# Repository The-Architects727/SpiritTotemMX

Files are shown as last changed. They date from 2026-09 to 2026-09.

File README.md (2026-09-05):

# SpiritTotemMX

A port of the [TOTEM](https://github.com/GEIGEIGEIST/TOTEM) split keyboard
to MX-style hot-swap switches, with a few of my own additions (per-half
battery-charge LEDs on the dongle, an on-demand battery check, and sleep
management for each half — see [Firmware](#firmware)).

This repo has everything needed to build one from scratch: the 3D-printable
case, the PCB design and fabrication files, ready-to-flash firmware, and
the full assembly guide below.

The layout is inspired by the original TOTEM — a printed test of that
shape was comfortable enough for my hands that I built the rest of this
board around it, redesigning the PCB and case for MX switches from
scratch. The XIAO boards sit on hot-swap headers rather than being
soldered in directly, so they can move to a different project later if
needed. Currently FDM printed in PLA with no tenting solution yet — both
are on the list for a future revision.

## Contents

- [What's in this repo](#whats-in-this-repo)
- [Bill of materials](#bill-of-materials)
- [Assembly](#assembly)
- [Keymap](#keymap)
- [Firmware](#firmware)
- [License](#license)

## What's in this repo

| Folder | Contents |
|---|---|
| [`Case/`](Case) | STL files for 3D printing the case and keycaps |
| [`PCB/`](PCB) | KiCad project source and fabrication-ready Gerbers/BOM/positions |
| [`Firmware/`](Firmware) | Pre-built `.uf2` firmware, ready to flash |

## Bill of materials

Links are the specific listings used for this build, not strict
requirements — quantities are usually a bulk pack, and most of these have
plenty of equivalent alternatives if a listing goes stale.

- 1 PCB — the left half, right half, and dongle are all panelized onto a
  single board you order as one piece (see [`PCB/`](PCB))
- 38× key switches — [Keychron Super Switch, tactile, 110-pack](https://www.amazon.com/dp/B0F9FJDWGZ)
- 38× Kailh hot-swap sockets — [Kailh CPG151101S11, 50-pack](https://www.amazon.com/dp/B0BVH6M5FP)
- 38× diodes (through-hole or SMD) — [1N4001, DO-41, 120-pack](https://www.amazon.com/dp/B0DN5YNFHQ)
  (1N4148 is the more common choice for keyboard matrices, but 1N4001 works
  fine here too)
- 3× Seeed Studio XIAO nRF52840 boards, with headers on —
  [Seeed Studio, 3-pack](https://www.seeedstudio.com/Seeed-Studio-XIAO-nRF52840-3PCS-p-5921.html)
- 2× JST 2.0 female wire connectors (battery leads for the two hand boards)
  and 4× JST 2.0 male PCB connectors — one kit covers both:
  [JST-PH 2.0mm 2-pin, male+female with 10cm wire, 20 sets](https://www.amazon.com/dp/B0D7Q9HJLQ)
- 2× through-hole PCB slide switches (mounted sideways so they poke out the
  side of the case) — [Chanzon SPDT 3mm slide switch, 70-pack](https://www.amazon.com/dp/B09R43HCY3)
- 2.54mm pitch headers for the XIAO standoffs — 60 pin positions total —
  [2.54mm male/female pin headers, 30-pack](https://www.amazon.com/dp/B0FCTSSLK9)
- 2× 3.7V JST 2.0 batteries, no more than 7mm thick × 20mm wide × 45mm long —
  [AKZYTUE 3.7V 750mAh LiPo, JST PH2.0](https://www.amazon.com/dp/B07TWHFW82)
- 2× 5mm LEDs
- 2× 330Ω resistors (through-hole or SMD)
- M2 brass heat-set inserts —
  [Pofsnnx M2 brass heat-set inserts, 250-pack](https://www.amazon.com/dp/B0FJXLNMLM)
- M2 screws: 6× 12mm, 1× 4mm —
  [KADRICK M2 hex socket button head screw assortment, 1000-pack](https://www.amazon.com/dp/B0DRCG3418)

## Assembly

### PCB and soldering

1. Break the panelized PCB apart into its 3 boards (left, right, dongle)
   along the mouse-bite tabs, and lightly sand the broken edges smooth.
2. Solder the diodes to the **top** face and the hot-swap sockets to the
   **underside**. The switchplate has cutouts to clear the diodes as long
   as they're soldered close to the board.
3. Solder the 2.54mm headers to the top face of each hand's board, where
   the XIAO will sit.
4. Solder the JST connectors and the slide power switch into place.
5. Solder a JST female connector pigtail to the underside of each hand's
   XIAO board, for its battery. This is the fiddliest step — put a small
   blob of solder on the pad first, then push the wire into the molten
   blob with the iron in one hand and a small pair of pliers in the other.
6. For the dongle: solder on the headers, then solder the two 5mm LEDs to
   the underside so they shine from the inside toward the outside edge,
   along with their resistors.

### Case

- `Top.stl` and `Bottom.stl` are single files — print one of each and
  mirror a second copy of each in your slicer for the other hand.
  `Switchplate.stl` and `Switchplate-left.stl` are **not** mirror images of
  each other — print each one exactly once.
- [`Case/KeyCaps/`](Case/KeyCaps) has the keycap profiles, designed to be
  printed flat on the bed while still having a swept (sculpted) profile —
  no supports needed despite the curve. Print 12× `Home`, 20×
  `Top-Bottom`, and 6× `Thumb` (38 keycaps total).
- Press a 2mm brass insert into the hole in the dongle base's dovetail.
- Press a heat-set insert into every standoff hole in each hand's bottom
  case piece.
- **Dongle:** drop the PCB+XIAO assembly into the bottom housing, slide the
  top piece on and push it forward to lock the board in place, then secure
  with a single M2×4mm screw.
- **Each hand:** place the PCB on the bottom case, then the switchplate
  over it (press a few switches into place to hold the sandwich together
  while you work), then the top plate, and secure with a 12–16mm screw in
  each top hole.

### First power-on

The dongle learns which half is "left" and which is "right" by whichever
one it bonds to first — so the very first time, power things on in this
order:

1. Everything off.
2. Plug in the dongle.
3. Power on the **left** half, and wait a moment.
4. Power on the **right** half.

After this first pairing, the two halves can be powered on in any order.

## Keymap

Colemak-DH based, 5 layers. `...` means "transparent" (falls through to
the layer below). A printable version with a visual key-by-key diagram of
every layer is at [`keymap-reference.pdf`](keymap-reference.pdf).

### Base

```
  Q      W      F      P      B        J      L      U      Y      '
  A      R      S      T      G        M      N      E      I      O
 Esc     Z      X      C      D      V        K      H      ,      .      /      -
   Ctrl/Del  Nav/Tab    Space     Shift/Ent  Sym/Bspc   Fun/\
```

### Nav

*Hold the left thumb's `Nav/Tab` key.*

```
 ...    ...    ...    ...    ...      ...    Home    Up    PgUp   End
 Gui    Alt    Ctrl   ...    ...      Del    Left   Down  Right   PgDn
 ...    ...    ...    ...    ...    ...      Ins    ...    ...    ...    ...    ...
     ...       ...       ...         ...       ...       ...
```

### Sym

*Hold the right thumb's `Sym/Bspc` key.*

```
  1      2      3      4      5        6      7      8      9      0
  !      @      #      $      %        ^      &      *      (      )
Studio   (      [      {      <      `        ~      >      }      ]      )     ...
     ...       ...       ...         ...       ...       ...
```

### Fun

*Hold the right thumb's `Fun/\` key.*

```
  F1     F2     F3     F4     F5       F6     F7     F8     F9    F10
 ...    ...    ...    ...    ...      ...    ...    ...    F11    F12
BatChk  Boot   ...    ...    ...    ...      ...    ...    ...    ...   ToGame  ...
     ...       ...       ...         ...       ...       ...
```

`BatChk` blinks the dongle's LEDs to report each half's battery charge in
10% steps. `Boot` reboots that half into its UF2 bootloader. `ToGame`
switches to the Game layer.

### Game

*Toggled from Fun's `ToGame` key; `ToBase` returns to Base.*

```
  T      Q      X      E      R        Y      U      I      O      P
  G      A      W      D      F        H      J      K      L      ;
 ...     B      Z      S      C      V        N      M      ,      .      /     ...
    Shift      Ctrl     Space       Enter      Bspc     ToBase
```

QWERTY, except W/S/X are rotated one column so A, W, and D all land on the
home row together with S directly beneath — this columnar layout puts W a
row above A/D by default, which doesn't rest as naturally for WASD as a
traditional keyboard's row stagger does. X moves up to W's old spot. The
thumb cluster is set up for typical games (Shift, Ctrl, Space on the left;
Enter, Backspace on the right) rather than mod-taps, since a key's brief
"tap" behavior is exactly the kind of thing you don't want fighting with
WASD-style movement.

## Firmware

[`Firmware/Colemak/`](Firmware/Colemak) has four ready-to-flash `.uf2`
files — one each for the left half, right half, dongle, and a
`settings_reset` image used to clear Bluetooth pairings if you ever need
to re-pair from scratch.

**To flash a board:** plug it into USB, double-tap its reset button to
drop it into bootloader mode (it shows up as a USB drive), then drag the
matching `.uf2` file onto that drive. Flash all three main boards; only
use `settings_reset` if you need to re-pair.

This firmware also includes a few extras beyond the stock TOTEM build:
per-half battery-charge LEDs on the dongle, an on-demand battery-level
check from the keyboard itself, and independent sleep for each half (with
a warning flash) that's triggered either manually or automatically when
the dongle's out of reach.

**Want to build it yourself, or modify it?** The buildable source and
GitHub Actions build workflow live in a separate repo,
[zmk-config-spirittotem](https://github.com/The-Architects727/zmk-config-spirittotem),
released under the MIT license.

## License

- **Case and PCB** (everything in [`Case/`](Case) and [`PCB/`](PCB)) are
  licensed [CC BY-SA 4.0](LICENSE): use, modify, and share freely, with
  credit, and any modified version you share stays under the same license.
- **Firmware** is not included as source here (see [Firmware](#firmware)) —
  the buildable source lives in
  [zmk-config-spirittotem](https://github.com/The-Architects727/zmk-config-spirittotem)
  under the MIT license. The pre-built `.uf2` binaries in
  [`Firmware/Colemak/`](Firmware/Colemak) are just compiled output from
  that source.

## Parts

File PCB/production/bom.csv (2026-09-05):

Designator | Footprint | Quantity | Value | LCSC Part #
_9, _8, _7, _6, _5, _4, _3, _2, |  | 9
D1, D10, D11, D12, D13, D14, D15, D16, D17, D18, D19, D2, D20, D21, D22, D23, D24, D25, D26, D27, D28, D29, D3_3, D3_2, D3, D30, D31, D32, D33, D34, D35, D36, D37, D38, D4, D5, D6, D7, D8, D9 | ComboDiode-SOD-Through | 40
L_BAT_BAT, L_XIAO_BAT, R_BAT_BAT, R_XIAO_BAT | JST_PH_B2B-PH-K_1x02_P2.00mm_Vertical | 4 | JST_PH_B2B-PH-K_1x02_P2.00mm_Vertical
L_SWITCH_SOCKET, R_SWITCH_SOCKET | PinSocket_1x03_P2.54mm_Vertical | 2 | PinSocket_1x03_P2.54mm_Vertical
S1, S10, S11, S12, S13, S14, S15, S16, S17, S18, S19, S2, S20, S21, S22, S23, S24, S25, S26, S27, S28, S29, S3, S30, S31, S32, S33, S34, S35, S36, S37, S38, S4, S5, S6, S7, S8, S9 | MX-ergogen | 38
U?_3, U?_2, U? | xiao-ble-tht | 3 | xiao-ble-thruhole

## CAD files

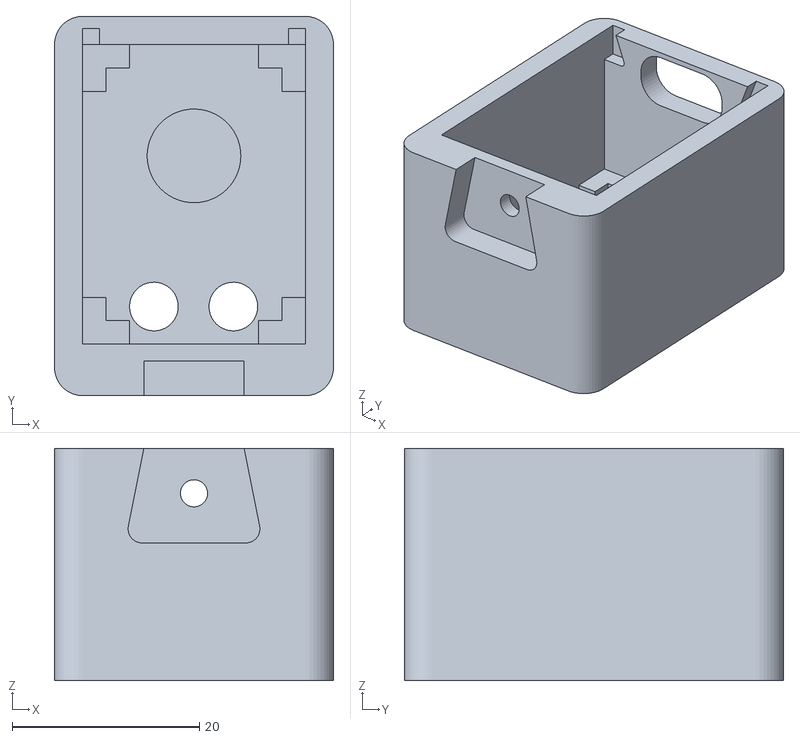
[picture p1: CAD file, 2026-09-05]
Case/Dongle/DongleBase.stl
29.8 x 40.5 x 24.8

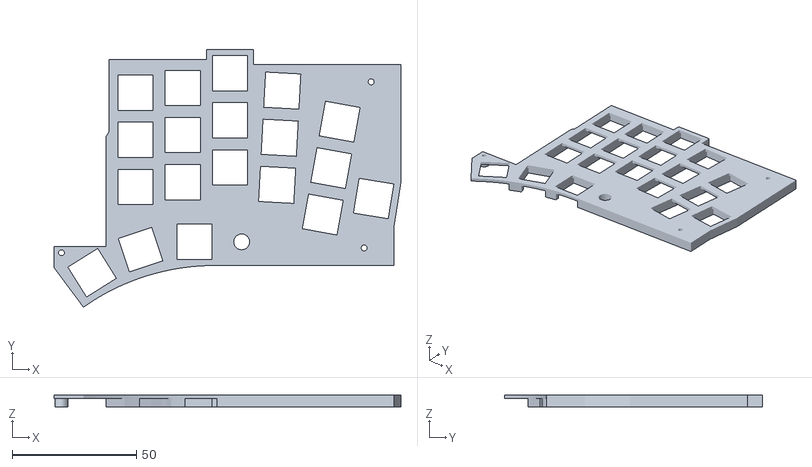
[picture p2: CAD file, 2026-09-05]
Case/Keyboard/Switchplate-left.stl
139.7 x 103.7 x 5.00

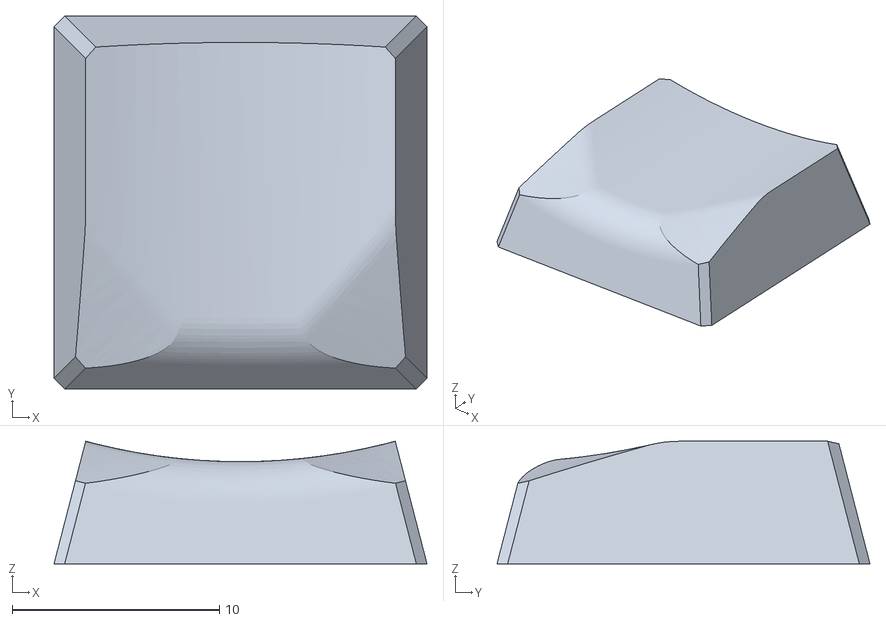
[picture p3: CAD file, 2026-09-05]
Case/KeyCaps/Thumb.stl
18.0 x 18.0 x 5.92

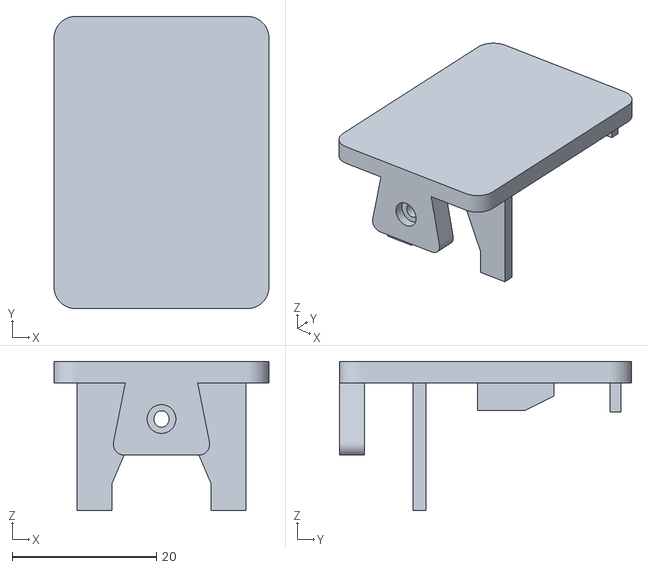
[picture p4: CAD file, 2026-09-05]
Case/Dongle/DongleTop.stl
29.8 x 40.5 x 20.7

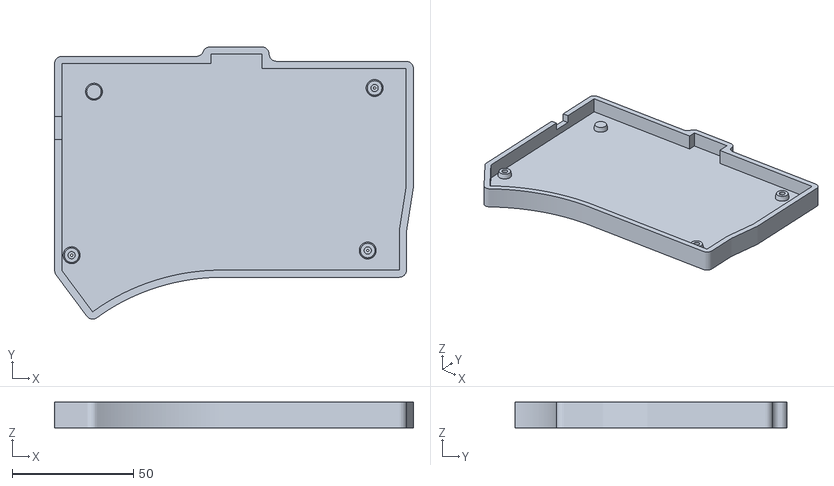
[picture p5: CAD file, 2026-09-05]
Case/Keyboard/Bottom.stl
147.8 x 112.1 x 10.6

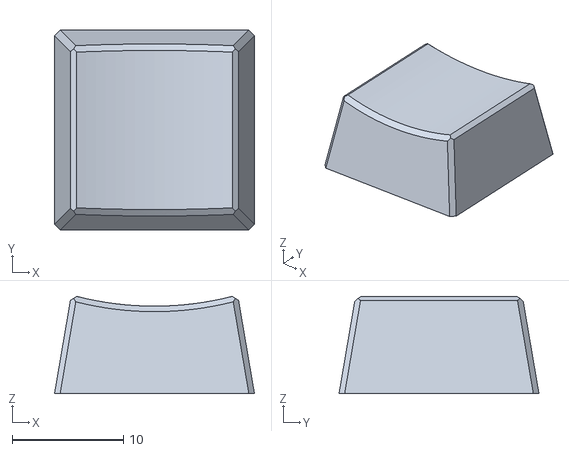
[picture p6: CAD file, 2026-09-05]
Case/KeyCaps/Home.stl
18.0 x 18.0 x 8.75

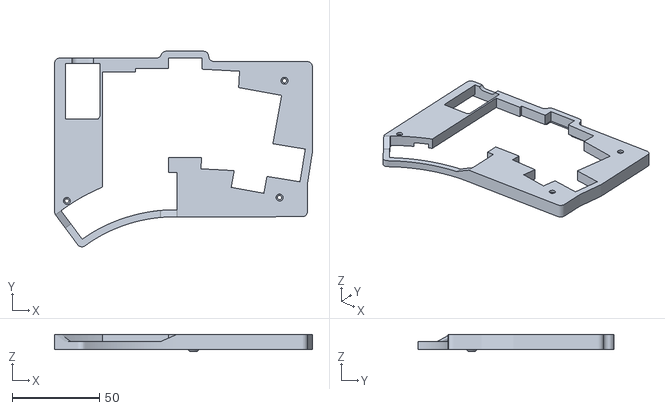
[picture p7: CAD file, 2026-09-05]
Case/Keyboard/Top.stl
147.8 x 112.1 x 9.90

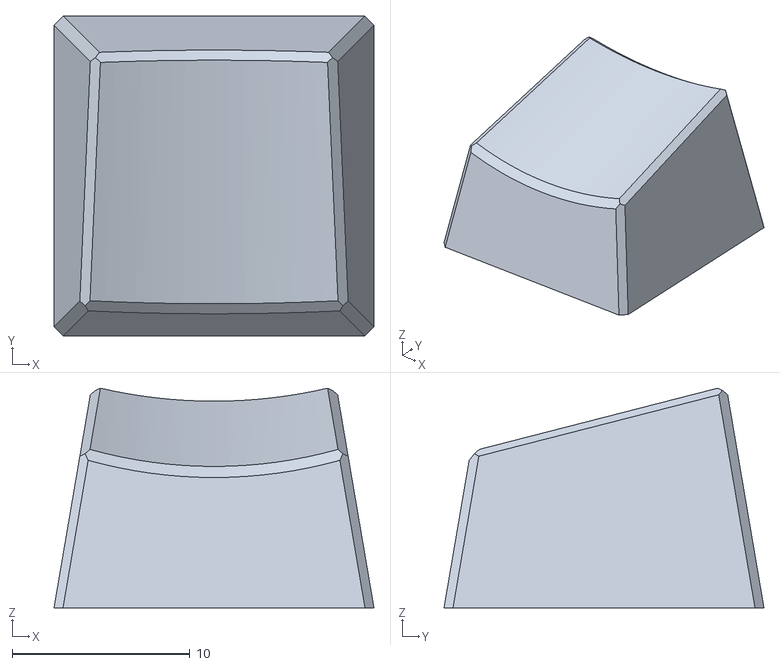
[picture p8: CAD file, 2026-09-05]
Case/KeyCaps/Top-Bottom.stl
18.0 x 18.0 x 12.4

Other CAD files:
Case/Keyboard/Switchplate.stl

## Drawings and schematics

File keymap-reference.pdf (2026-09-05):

# Totem keymap reference

## Base

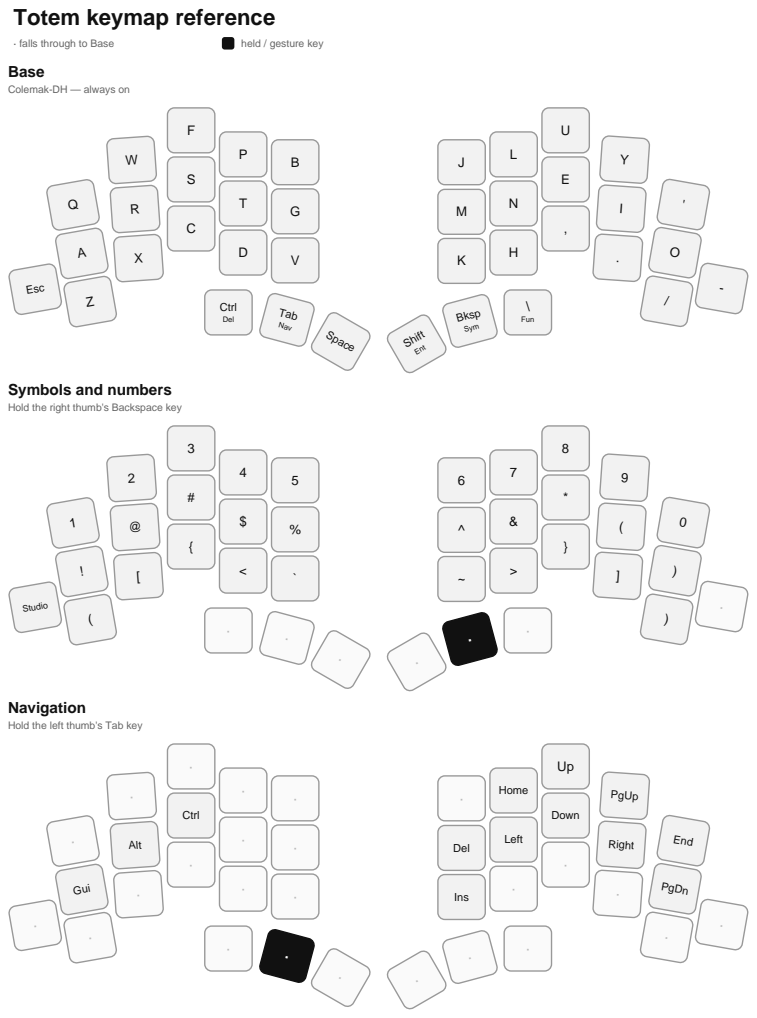
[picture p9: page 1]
· falls through to Base; held / gesture key; Esc; Ctrl; Del; Tab; Nav Space; Shift Ent; Bksp; Sym; Fun; Studio; Home; PgUp; End; Gui; Alt; · Del; Left; Down; Right; PgDn; Ins

Colemak-DH — always on

Symbols and numbers
Hold the right thumb's Backspace key

Navigation
Hold the left thumb's Tab key

# Totem keymap reference (cont.)

## Functions

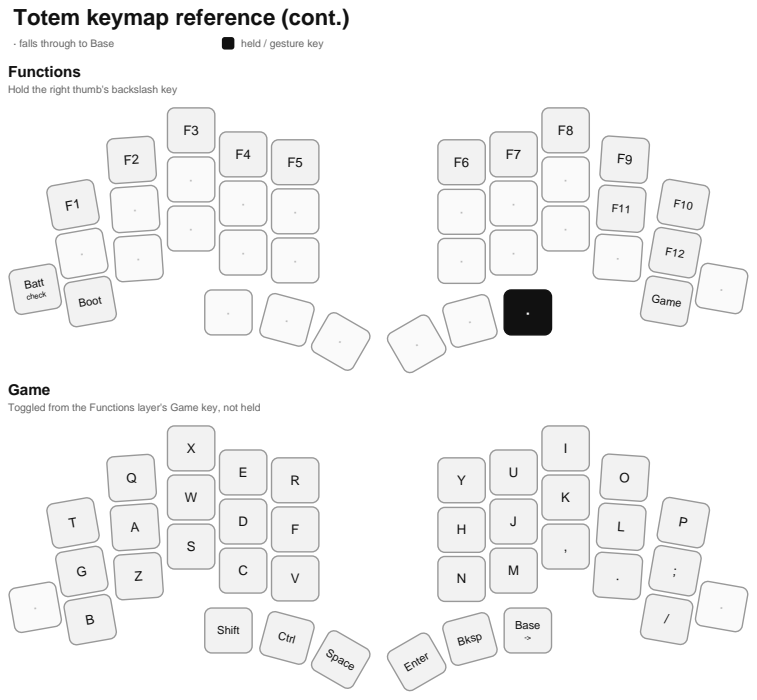
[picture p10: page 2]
· falls through to Base; held / gesture key; Batt check; Boot; Game; Shift; Ctrl; Space; Enter; Bksp; Base

Hold the right thumb's backslash key

Game
Toggled from the Functions layer's Game key, not held

# Sleep gesture

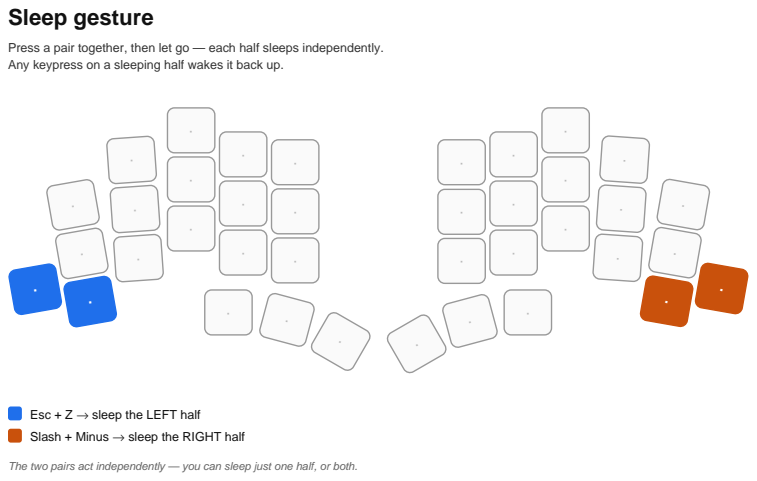
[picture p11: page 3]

Press a pair together, then let go — each half sleeps independently.
Any keypress on a sleeping half wakes it back up.

Esc + Z → sleep the LEFT half
Slash + Minus → sleep the RIGHT half

The two pairs act independently — you can sleep just one half, or both.

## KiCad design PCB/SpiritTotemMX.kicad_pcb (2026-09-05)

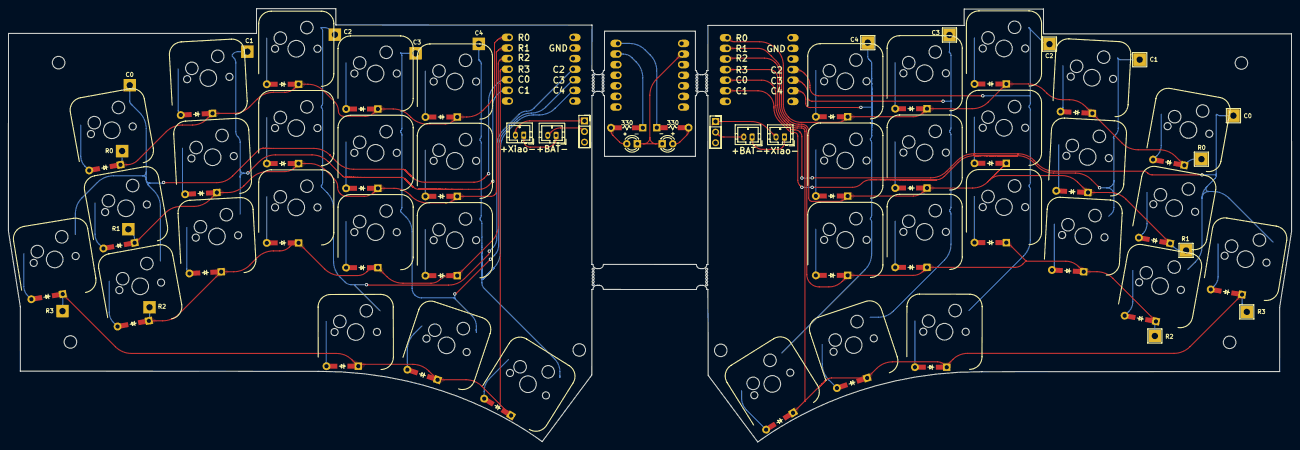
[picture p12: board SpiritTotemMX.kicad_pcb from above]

Board: 2 copper layers, 307.3 x 103.8 mm, 87 parts (0 on the bottom side), 64 nets.

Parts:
D1, D2, D3, D3#2, D3#3, D4, D5, D6, D7, D8, D9, D10, D11, D12, D13, D14, D15, D16, D17, D18, D19, D20, D21, D22, D23, D24, D25, D26, D27, D28, D29, D30, D31, D32, D33, D34, D35, D36, D37, D38: ComboDiode-SOD-Through
L_Bat_Bat: JST_PH_B2B-PH-K_1x02_P2.00mm_Vertical
L_Switch_Socket: PinSocket_1x03_P2.54mm_Vertical
L_Xiao_Bat: JST_PH_B2B-PH-K_1x02_P2.00mm_Vertical
R_Bat_Bat: JST_PH_B2B-PH-K_1x02_P2.00mm_Vertical
R_Switch_Socket: PinSocket_1x03_P2.54mm_Vertical
R_Xiao_Bat: JST_PH_B2B-PH-K_1x02_P2.00mm_Vertical
S1, S2, S3, S4, S5, S6, S7, S8, S9, S10, S11, S12, S13, S14, S15, S16, S17, S18, S19, S20, S21, S22, S23, S24, S25, S26, S27, S28, S29, S30, S31, S32, S33, S34, S35, S36, S37, S38: MX-ergogen
U?: xiao-ble-thruhole; xiao-ble-tht
U?#2, U?#3: xiao-ble-thruhole; xiao-ble-tht

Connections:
Dongle_L: D3#3.1, U?#2.2
Dongle_R: D3#2.1, U?#2.1
L_Bat+: L_Switch_Socket.1, L_Switch_Socket.3, L_Xiao_Bat.2
L_Bat-: L_Bat_Bat.1, L_Xiao_Bat.1
L_Batery+: L_Bat_Bat.2, L_Switch_Socket.2
L_Col0: S32.2, S33.2, S34.2, S35.2, U?.5
L_Col1: S29.2, S30.2, S31.2, U?.6
L_Col2: S26.2, S27.2, S28.2, S36.2, U?.11
L_Col3: S23.2, S24.2, S25.2, S37.2, U?.10
L_Col4: S20.2, S21.2, S22.2, S38.2, U?.9
L_Row0: D22.1, D25.1, D28.1, D31.1, D34.1, U?.1
L_Row1: D21.1, D24.1, D27.1, D30.1, D33.1, U?.2
L_Row2: D20.1, D23.1, D26.1, D29.1, D32.1, U?.3
L_Row3: D35.1, D36.1, D37.1, D38.1, U?.4
R_Bat+: R_Switch_Socket.1, R_Switch_Socket.3, R_Xiao_Bat.2
R_Bat-: R_Bat_Bat.1, R_Xiao_Bat.1
R_Batery+: R_Bat_Bat.2, R_Switch_Socket.2
R_Col0: S13.2, S14.2, S15.2, S16.2, U?#3.5
R_Col1: S10.2, S11.2, S12.2, U?#3.6
R_Col2: S7.2, S8.2, S9.2, S17.2, U?#3.11
R_Col3: S4.2, S5.2, S6.2, S18.2, U?#3.10
R_Col4: S1.2, S2.2, S3.2, S19.2, U?#3.9
R_Row0: D3.1, D6.1, D9.1, D12.1, D15.1, U?#3.1
R_Row1: D2.1, D5.1, D8.1, D11.1, D14.1, U?#3.2
R_Row2: D1.1, D4.1, D7.1, D10.1, D13.1, U?#3.3
R_Row3: D16.1, D17.1, D18.1, D19.1, U?#3.4
left_matrix_index_bottom: D23.2, S23.1
left_matrix_index_home: D24.2, S24.1
left_matrix_index_top: D25.2, S25.1
left_matrix_inner_bottom: D20.2, S20.1
left_matrix_inner_home: D21.2, S21.1
left_matrix_inner_top: D22.2, S22.1
left_matrix_middle_bottom: D26.2, S26.1
left_matrix_middle_home: D27.2, S27.1
left_matrix_middle_top: D28.2, S28.1
left_matrix_pinky_bottom: D32.2, S32.1
left_matrix_pinky_home: D33.2, S33.1
left_matrix_pinky_top: D34.2, S34.1
left_matrix_ring_bottom: D29.2, S29.1
left_matrix_ring_home: D30.2, S30.1
left_matrix_ring_top: D31.2, S31.1
left_pinky_outer_a_key: D35.2, S35.1
left_thumb_inner_a_thumb: D36.2, S36.1
left_thumb_mid_a_thumb: D37.2, S37.1
left_thumb_outer_a_thumb: D38.2, S38.1
right_matrix_index_bottom: D4.2, S4.1
right_matrix_index_home: D5.2, S5.1
right_matrix_index_top: D6.2, S6.1
right_matrix_inner_bottom: D1.2, S1.1
right_matrix_inner_home: D2.2, S2.1
right_matrix_inner_top: D3.2, S3.1
right_matrix_middle_bottom: D7.2, S7.1
right_matrix_middle_home: D8.2, S8.1
right_matrix_middle_top: D9.2, S9.1
right_matrix_pinky_bottom: D13.2, S13.1
right_matrix_pinky_home: D14.2, S14.1
right_matrix_pinky_top: D15.2, S15.1
right_matrix_ring_bottom: D10.2, S10.1
right_matrix_ring_home: D11.2, S11.1
right_matrix_ring_top: D12.2, S12.1
right_pinky_outer_a_key: D16.2, S16.1
right_thumb_inner_a_thumb: D17.2, S17.1
right_thumb_mid_a_thumb: D18.2, S18.1
right_thumb_outer_a_thumb: D19.2, S19.1

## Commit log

2026-09-05 Initial commit: case, PCB, and pre-built firmware for SpiritTotemMX
    A port of the TOTEM split keyboard to MX-style hot-swap switches, with
    its own PCB and case. Firmware is included as ready-to-flash binaries
    only (Firmware/Colemak/) - the buildable source lives separately in
    zmk-config-spirittotem under the MIT license, kept apart from this
    repo so the firmware license doesn't have to match the hardware's.
    Case and PCB are licensed CERN-OHL-P, matching the original TOTEM
    hardware design this is derived from (see LICENSE).
    Excluded from version control: KiCad editor backups/autosave
    snapshots, the fp-info-cache and .kicad_prl local-state files, and a
    stale duplicate Gerber export supersede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
    [Bottom.stl, DongleBase.stl, DongleTop.stl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]
2026-09-05 Add corrected keymap reference PDF
    The prior draft's sleep-combo page described the old removed behavior
    (a single 4-key combo requiring both halves at once). Regenerated from
    the actual physical key coordinates in totem.dtsi, with page 3 now
    showing the real behavior: Esc+Z and Slash+Minus are two independent
    per-half gestures, not one combined combo.
    Also added .gitattributes marking pdf/uf2/stl/zip as binary - without
    it, a clone with core.autocrlf=true (the common Windows default, and
    what this machine uses) would rewrite bare LF bytes to CRLF in these
    files on checkout and corrupt them. Nothing already pushed was
    affected (git's own heuristic had already stored the STL/UF2 files
    correc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
2026-09-05 Add sourcing links to the BOM
    Links point to the specific listings actually used for this build,
    noted as such rather than as strict requirements - most BOM items here
    have plenty of equivalent alternatives.
2026-09-05 Add keycap STLs
    Home, Thumb, and Top-Bottom profiles, designed to print flat on the
    bed while still having a swept (sculpted) profile - no supports
    needed despite the curve.
    [Home.stl, Thumb.stl, Top-Bottom.stl]
2026-09-05 Note keycap print quantities per profile
    12x Home, 20x Top-Bottom, 6x Thumb - 38 total, matching the key count.
2026-09-05 Switch hardware license to CC BY-SA 4.0, credit TOTEM as inspiration
    CERN-OHL-P framed this as a modified derivative of GEIST's TOTEM
    design, which overstated the relationship - the PCB traces, case, and
    switch footprint (MX vs the original's Choc) were independently
    redesigned from scratch, with only the general layout concept carried
    over. CC BY-SA 4.0 is more standard in the maker/3D-printing community
    and better matches what's actually being licensed: original work,
    credited to what inspired it, not a derivative under someone else's
    hardware license.
    Added a short note up top on that inspiration and current build status
    (PLA, no tenting yet), and trimmed a redundant explanation from the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
